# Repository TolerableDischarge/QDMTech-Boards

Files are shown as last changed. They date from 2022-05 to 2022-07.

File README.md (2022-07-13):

# QDMTech-Boards
A repo of all the boards designed by QuantumDarkMatter Tech.
v0.1 is very bad since I was learning as I was going for my Uni Project. There's a first time for everything I guess.
IMPORTANT: Right now the only thing under MIT license is the ZMK firmware files, the rest is a little murky. v0.2 will be MIT compatible.

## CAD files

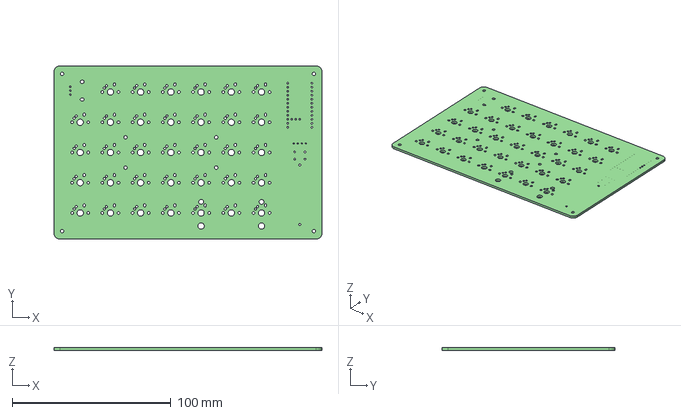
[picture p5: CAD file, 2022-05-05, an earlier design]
mk_01/v0.1/Hardware/mk_01_LHS/mk_01_LHS.step
168.9 x 109.2 x 1.60 mm

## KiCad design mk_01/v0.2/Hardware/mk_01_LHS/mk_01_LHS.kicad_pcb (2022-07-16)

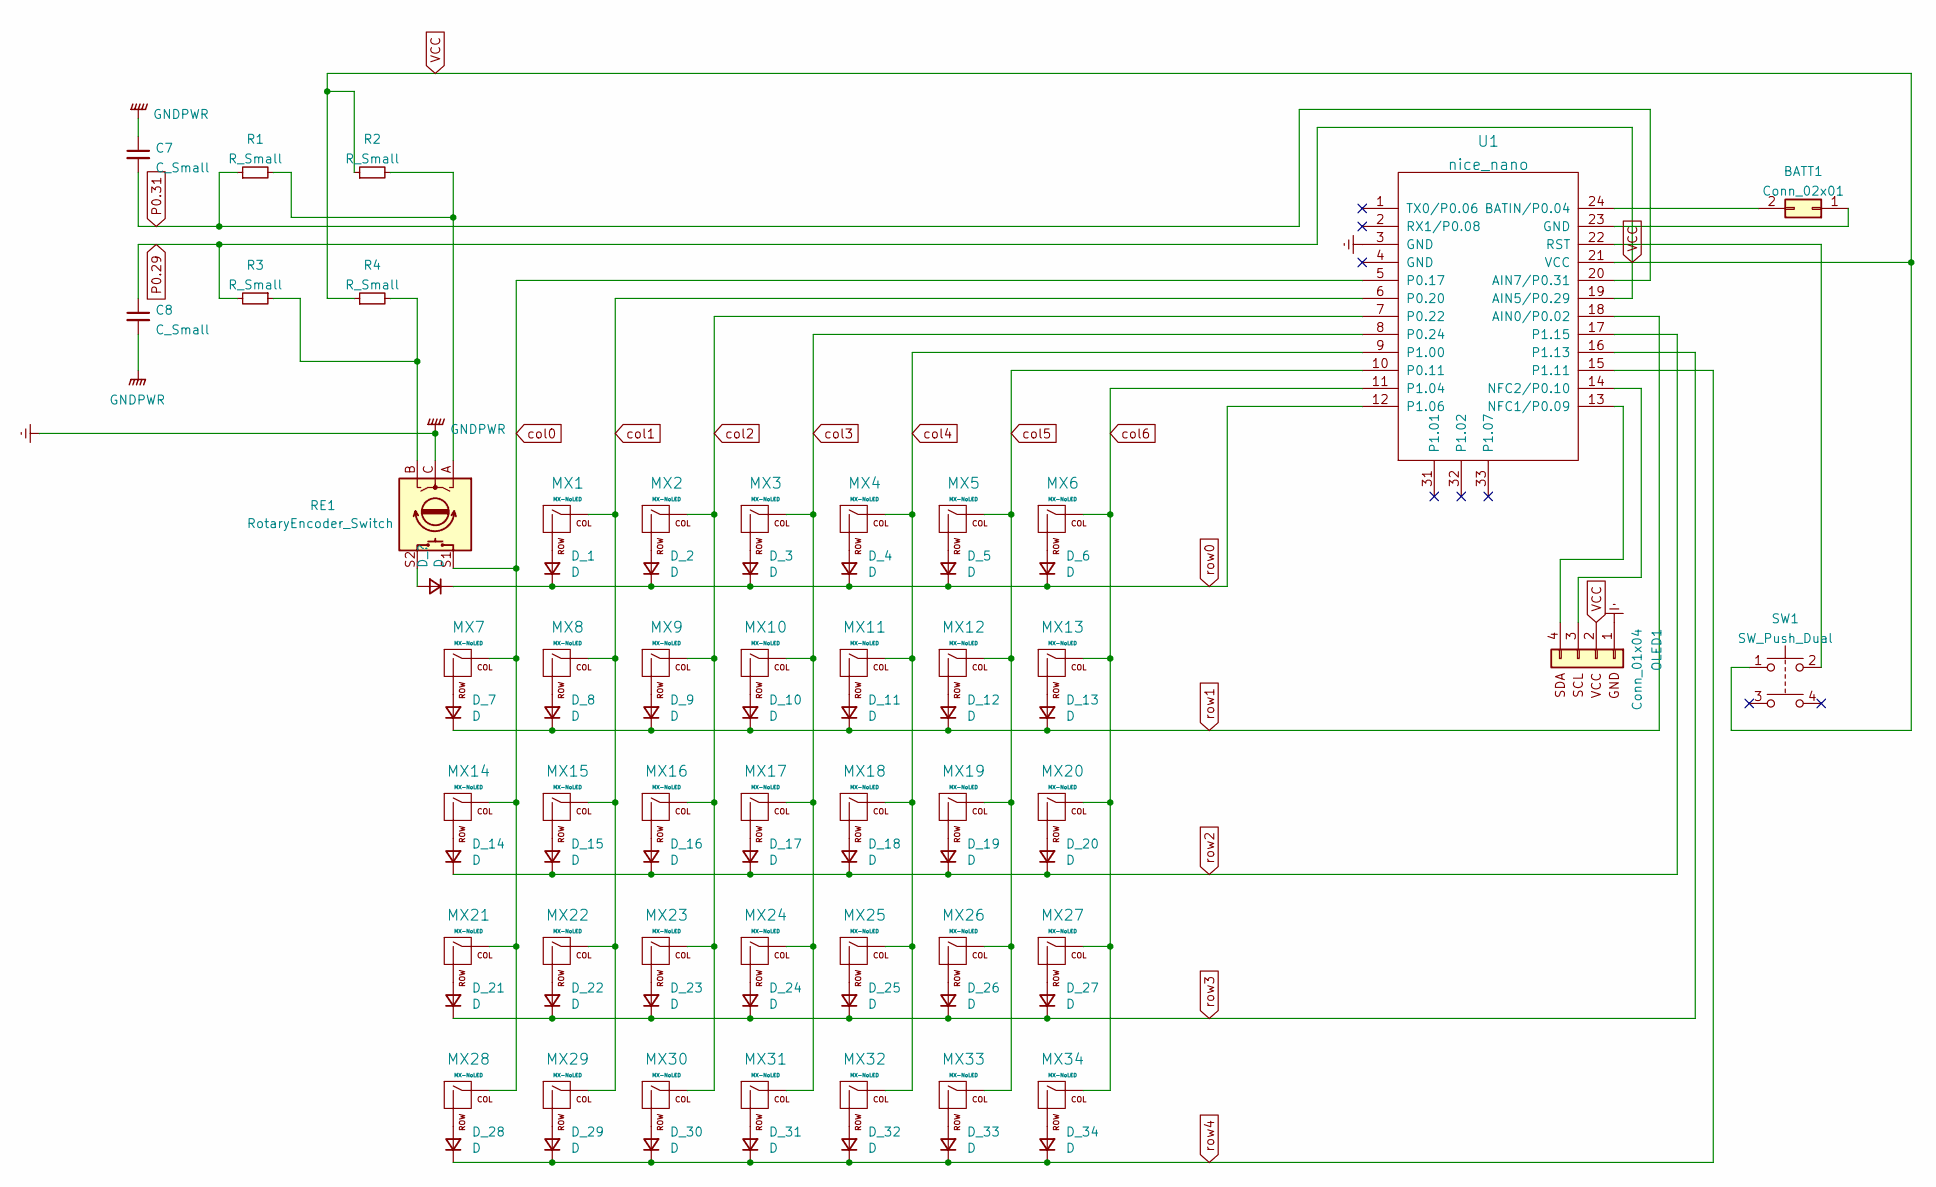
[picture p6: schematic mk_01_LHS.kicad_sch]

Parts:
BATT1: Conn_02x01; C_Rect_L41.5mm_W20.0mm_P37.50mm_MKS4
C7, C8: C_Small; C_0805_2012Metric_Pad1.18x1.45mm_HandSolder
D_1, D_2, D_3, D_4, D_5, D_6, D_7, D_8, D_9, D_10, D_11, D_12, D_13, D_14, D_15, D_16, D_17, D_18, D_19, D_20, D_21, D_22, D_23, D_24, D_25, D_26, D_27, D_28, D_29, D_30, D_31, D_32, D_33, D_34: D; D_SOD-123
MX1, MX2, MX3, MX4, MX5, MX6, MX7, MX8, MX9, MX10, MX11, MX12, MX13, MX14, MX15, MX16, MX17, MX18, MX19, MX20, MX21, MX22, MX23, MX24, MX25, MX26, MX27, MX28, MX29, MX30, MX31, MX32, MX33, MX34: MX-NoLED; MXOnly-1U-Hotswap-NoLED
OLED1: Conn_01x04; OLED_4Pin
R1, R2, R3, R4: R_Small; R_0805_2012Metric_Pad1.20x1.40mm_HandSolder
RE1: RotaryEncoder_Switch; RotaryEncoder_Alps_EC11E-Switch_Vertical_H20mm
SW1: SW_Push_Dual; SW_PUSH_6mm_H5mm
U1: nice_nano

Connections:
Earth: C7.1, C8.2, OLED1.1, RE1.C, U1.3 (GND), U1.4 (GND)
unnamed: BATT1.1, U1.23 (GND)
unnamed: BATT1.2, U1.24 (BATIN/P0.04)
unnamed: D_1.2 (A), MX1.2 (ROW)
unnamed: D_2.2 (A), MX2.2 (ROW)
unnamed: D_3.2 (A), MX3.2 (ROW)
unnamed: D_4.2 (A), MX4.2 (ROW)
unnamed: D_5.2 (A), MX5.2 (ROW)
unnamed: D_6.2 (A), MX6.2 (ROW)
unnamed: D_7.2 (A), MX7.2 (ROW)
unnamed: D_8.2 (A), MX8.2 (ROW)
unnamed: D_9.2 (A), MX9.2 (ROW)
unnamed: D_10.2 (A), MX10.2 (ROW)
unnamed: D_11.2 (A), MX11.2 (ROW)
unnamed: D_12.2 (A), MX12.2 (ROW)
unnamed: D_13.2 (A), MX13.2 (ROW)
unnamed: D_14.2 (A), MX14.2 (ROW)
unnamed: D_15.2 (A), MX15.2 (ROW)
unnamed: D_16.2 (A), MX16.2 (ROW)
unnamed: D_17.2 (A), MX17.2 (ROW)
unnamed: D_18.2 (A), MX18.2 (ROW)
unnamed: D_19.2 (A), MX19.2 (ROW)
unnamed: D_20.2 (A), MX20.2 (ROW)
unnamed: D_21.2 (A), MX21.2 (ROW)
unnamed: D_22.2 (A), MX22.2 (ROW)
unnamed: D_23.2 (A), MX23.2 (ROW)
unnamed: D_24.2 (A), MX24.2 (ROW)
unnamed: D_25.2 (A), MX25.2 (ROW)
unnamed: D_26.2 (A), MX26.2 (ROW)
unnamed: D_27.2 (A), MX27.2 (ROW)
unnamed: D_28.2 (A), MX28.2 (ROW)
unnamed: D_29.2 (A), MX29.2 (ROW)
unnamed: D_30.2 (A), MX30.2 (ROW)
unnamed: D_31.2 (A), MX31.2 (ROW)
unnamed: D_32.2 (A), MX32.2 (ROW)
unnamed: D_33.2 (A), MX33.2 (ROW)
unnamed: D_34.2 (A), MX34.2 (ROW)
unnamed: OLED1.3, U1.14 (NFC2/P0.10)
unnamed: OLED1.4, U1.13 (NFC1/P0.09)
unnamed: R1.2, R2.2, RE1.A
unnamed: R3.1, R4.2, RE1.B
unnamed 41: RE1.S2; also elsewhere on the board
unnamed: SW1.2, U1.22 (RST)
P0.31: C7.2, R1.1, U1.20 (AIN7/P0.31)
col0: MX7.1 (COL), MX14.1 (COL), MX21.1 (COL), MX28.1 (COL), RE1.S1, U1.5 (P0.17)
col1: MX1.1 (COL), MX8.1 (COL), MX15.1 (COL), MX22.1 (COL), MX29.1 (COL), U1.6 (P0.20)
col2: MX2.1 (COL), MX9.1 (COL), MX16.1 (COL), MX23.1 (COL), MX30.1 (COL), U1.7 (P0.22)
col3: MX3.1 (COL), MX10.1 (COL), MX17.1 (COL), MX24.1 (COL), MX31.1 (COL), U1.8 (P0.24)
col4: MX4.1 (COL), MX11.1 (COL), MX18.1 (COL), MX25.1 (COL), MX32.1 (COL), U1.9 (P1.00)
col5: MX5.1 (COL), MX12.1 (COL), MX19.1 (COL), MX26.1 (COL), MX33.1 (COL), U1.10 (P0.11)
col6: MX6.1 (COL), MX13.1 (COL), MX20.1 (COL), MX27.1 (COL), MX34.1 (COL), U1.11 (P1.04)
row0: D_1.1 (K), D_2.1 (K), D_3.1 (K), D_4.1 (K), D_5.1 (K), D_6.1 (K), U1.12 (P1.06); also elsewhere on the board
row1: D_7.1 (K), D_8.1 (K), D_9.1 (K), D_10.1 (K), D_11.1 (K), D_12.1 (K), D_13.1 (K), U1.18 (AIN0/P0.02)
row2: D_14.1 (K), D_15.1 (K), D_16.1 (K), D_17.1 (K), D_18.1 (K), D_19.1 (K), D_20.1 (K), U1.17 (P1.15)
row3: D_21.1 (K), D_22.1 (K), D_23.1 (K), D_24.1 (K), D_25.1 (K), D_26.1 (K), D_27.1 (K), U1.16 (P1.13)
row4: D_28.1 (K), D_29.1 (K), D_30.1 (K), D_31.1 (K), D_32.1 (K), D_33.1 (K), D_34.1 (K), U1.15 (P1.11)

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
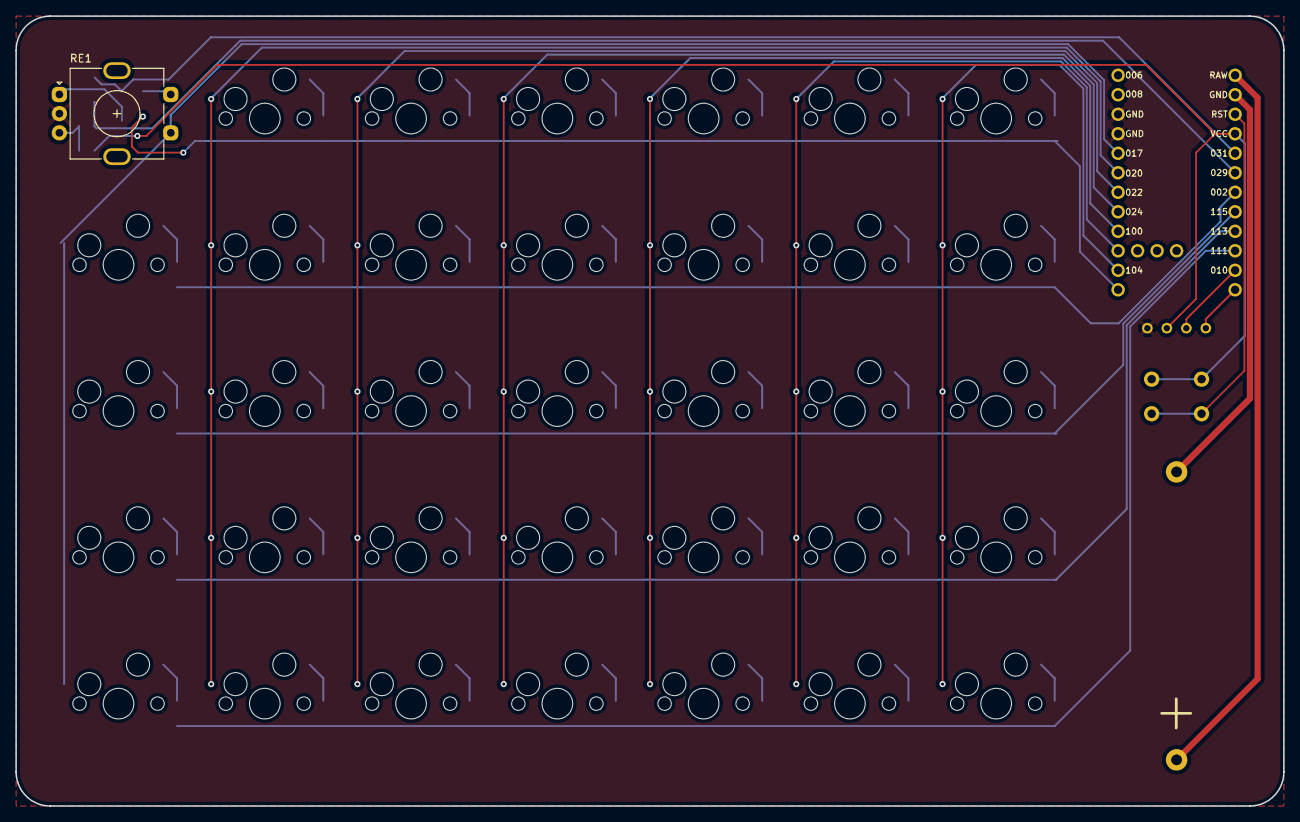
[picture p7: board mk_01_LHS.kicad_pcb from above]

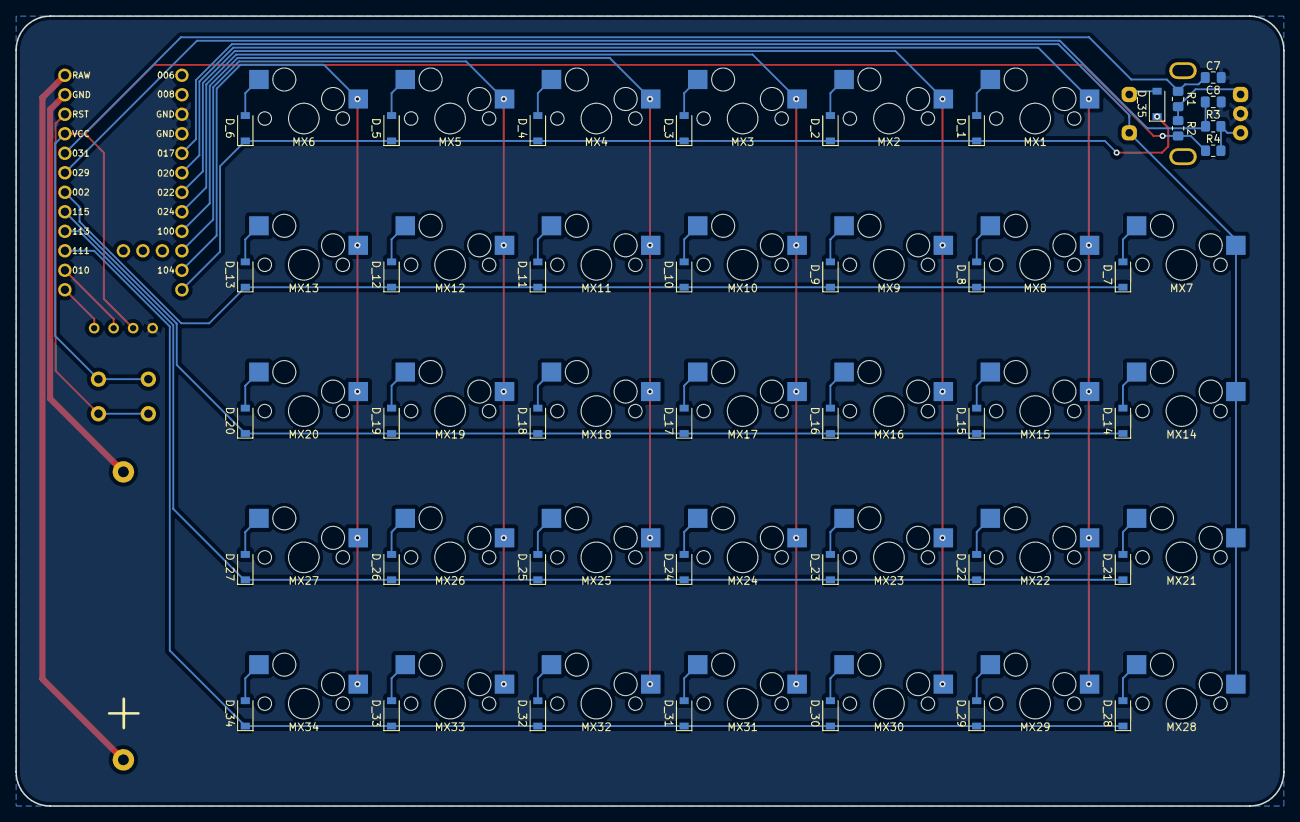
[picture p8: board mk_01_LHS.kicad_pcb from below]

Board: 2 copper layers, 165.1 x 102.9 mm, 80 parts (41 on the bottom side), 58 nets.

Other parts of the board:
D_35: D; D_SOD-123

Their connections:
unnamed 41: D_35.2 (A); also elsewhere on the board
row0: D_35.1 (K); also elsewhere on the board

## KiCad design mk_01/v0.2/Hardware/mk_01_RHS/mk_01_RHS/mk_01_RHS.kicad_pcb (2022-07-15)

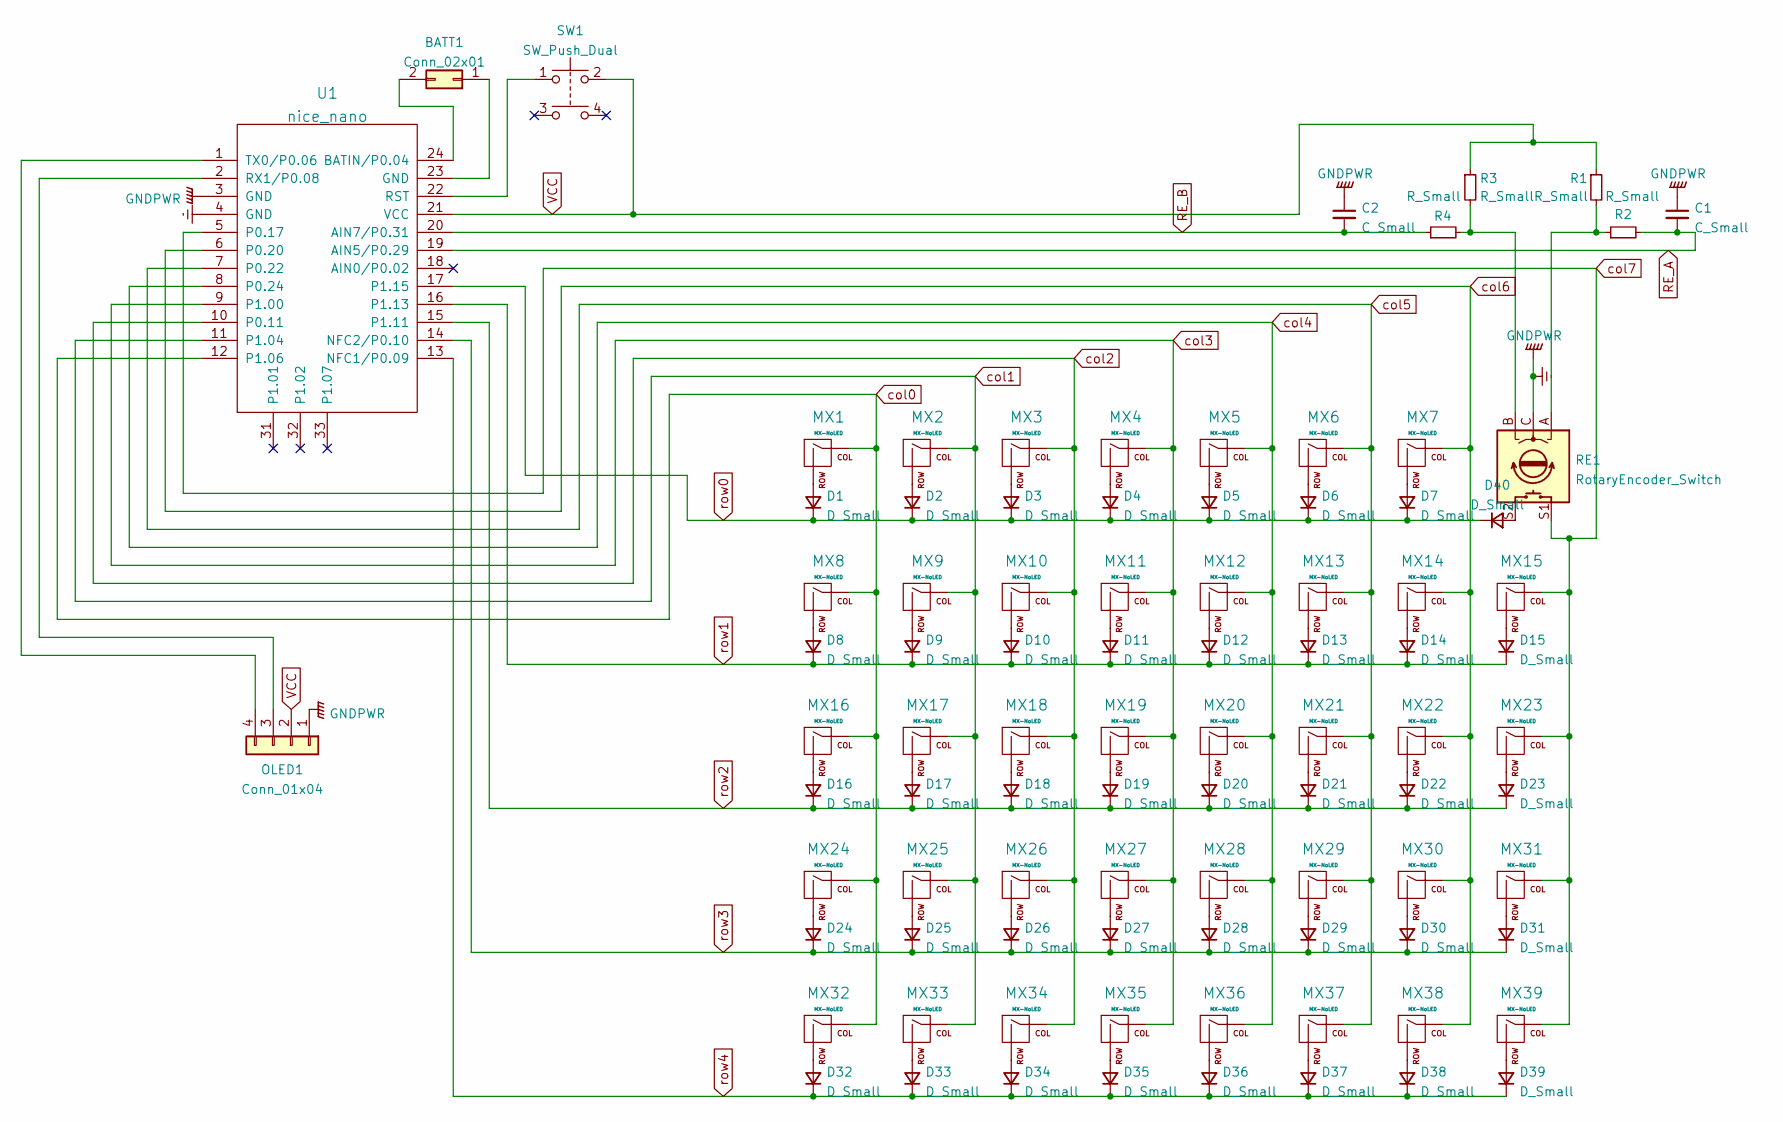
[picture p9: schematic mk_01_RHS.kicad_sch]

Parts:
BATT1: Conn_02x01; C_Rect_L41.5mm_W20.0mm_P37.50mm_MKS4
C1, C2: C_Small; C_0805_2012Metric_Pad1.18x1.45mm_HandSolder
D1, D2, D3, D4, D5, D6, D7, D8, D9, D10, D11, D12, D13, D14, D15, D16, D17, D18, D19, D20, D21, D22, D23, D24, D25, D26, D27, D28, D29, D30, D31, D32, D33, D34, D35, D36, D37, D38, D39, D40: D_Small; D_SOD-123
MX1, MX2, MX3, MX4, MX5, MX6, MX7, MX8, MX9, MX10, MX11, MX12, MX13, MX14, MX15, MX16, MX17, MX18, MX19, MX20, MX21, MX22, MX23, MX24, MX25, MX26, MX27, MX28, MX29, MX30, MX31, MX32, MX33, MX34, MX35, MX36, MX37, MX38, MX39: MX-NoLED; MXOnly-1U-Hotswap-NoLED
OLED1: Conn_01x04; OLED_4Pin
R1, R2, R3, R4: R_Small; R_0805_2012Metric_Pad1.20x1.40mm_HandSolder
RE1: RotaryEncoder_Switch; RotaryEncoder_Alps_EC11E-Switch_Vertical_H20mm
SW1: SW_Push_Dual; SW_PUSH_6mm_H5mm
U1: nice_nano

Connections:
Earth: C1.1, C2.1, OLED1.1, RE1.C, U1.3 (GND), U1.4 (GND)
unnamed: BATT1.1, U1.23 (GND)
unnamed: BATT1.2, U1.24 (BATIN/P0.04)
unnamed: D1.2 (A), MX1.2 (ROW)
unnamed: D2.2 (A), MX2.2 (ROW)
unnamed: D3.2 (A), MX3.2 (ROW)
unnamed: D4.2 (A), MX4.2 (ROW)
unnamed: D5.2 (A), MX5.2 (ROW)
unnamed: D6.2 (A), MX6.2 (ROW)
unnamed: D7.2 (A), MX7.2 (ROW)
unnamed: D8.2 (A), MX8.2 (ROW)
unnamed: D9.2 (A), MX9.2 (ROW)
unnamed: D10.2 (A), MX10.2 (ROW)
unnamed: D11.2 (A), MX11.2 (ROW)
unnamed: D12.2 (A), MX12.2 (ROW)
unnamed: D13.2 (A), MX13.2 (ROW)
unnamed: D14.2 (A), MX14.2 (ROW)
unnamed: D15.2 (A), MX15.2 (ROW)
unnamed: D16.2 (A), MX16.2 (ROW)
unnamed: D17.2 (A), MX17.2 (ROW)
unnamed: D18.2 (A), MX18.2 (ROW)
unnamed: D19.2 (A), MX19.2 (ROW)
unnamed: D20.2 (A), MX20.2 (ROW)
unnamed: D21.2 (A), MX21.2 (ROW)
unnamed: D22.2 (A), MX22.2 (ROW)
unnamed: D23.2 (A), MX23.2 (ROW)
unnamed: D24.2 (A), MX24.2 (ROW)
unnamed: D25.2 (A), MX25.2 (ROW)
unnamed: D26.2 (A), MX26.2 (ROW)
unnamed: D27.2 (A), MX27.2 (ROW)
unnamed: D28.2 (A), MX28.2 (ROW)
unnamed: D29.2 (A), MX29.2 (ROW)
unnamed: D30.2 (A), MX30.2 (ROW)
unnamed: D31.2 (A), MX31.2 (ROW)
unnamed: D32.2 (A), MX32.2 (ROW)
unnamed: D33.2 (A), MX33.2 (ROW)
unnamed: D34.2 (A), MX34.2 (ROW)
unnamed: D35.2 (A), MX35.2 (ROW)
unnamed: D36.2 (A), MX36.2 (ROW)
unnamed: D37.2 (A), MX37.2 (ROW)
unnamed: D38.2 (A), MX38.2 (ROW)
unnamed: D39.2 (A), MX39.2 (ROW)
unnamed: D40.2 (A), RE1.S2
unnamed: R3.2, R4.2, RE1.B
unnamed: R1.2, R2.1, RE1.A
unnamed: SW1.1, U1.22 (RST)
unnamed: OLED1.4, U1.1 (TX0/P0.06)
unnamed: OLED1.3, U1.2 (RX1/P0.08)
RE_A: C1.2, R2.2, U1.19 (AIN5/P0.29)
RE_B: C2.2, R4.1, U1.20 (AIN7/P0.31)
VCC: OLED1.2, R1.1, R3.1, SW1.2, U1.21 (VCC)
col0: MX1.1 (COL), MX8.1 (COL), MX16.1 (COL), MX24.1 (COL), MX32.1 (COL), U1.12 (P1.06)
col1: MX2.1 (COL), MX9.1 (COL), MX17.1 (COL), MX25.1 (COL), MX33.1 (COL), U1.11 (P1.04)
col2: MX3.1 (COL), MX10.1 (COL), MX18.1 (COL), MX26.1 (COL), MX34.1 (COL), U1.10 (P0.11)
col3: MX4.1 (COL), MX11.1 (COL), MX19.1 (COL), MX27.1 (COL), MX35.1 (COL), U1.9 (P1.00)
col4: MX5.1 (COL), MX12.1 (COL), MX20.1 (COL), MX28.1 (COL), MX36.1 (COL), U1.8 (P0.24)
col5: MX6.1 (COL), MX13.1 (COL), MX21.1 (COL), MX29.1 (COL), MX37.1 (COL), U1.7 (P0.22)
col6: MX7.1 (COL), MX14.1 (COL), MX22.1 (COL), MX30.1 (COL), MX38.1 (COL), U1.6 (P0.20)
col7: MX15.1 (COL), MX23.1 (COL), MX31.1 (COL), MX39.1 (COL), RE1.S1, U1.5 (P0.17)
row0: D1.1 (K), D2.1 (K), D3.1 (K), D4.1 (K), D5.1 (K), D6.1 (K), D7.1 (K), D40.1 (K), U1.17 (P1.15)
row1: D8.1 (K), D9.1 (K), D10.1 (K), D11.1 (K), D12.1 (K), D13.1 (K), D14.1 (K), D15.1 (K), U1.16 (P1.13)
row2: D16.1 (K), D17.1 (K), D18.1 (K), D19.1 (K), D20.1 (K), D21.1 (K), D22.1 (K), D23.1 (K), U1.15 (P1.11)
row3: D24.1 (K), D25.1 (K), D26.1 (K), D27.1 (K), D28.1 (K), D29.1 (K), D30.1 (K), D31.1 (K), U1.14 (NFC2/P0.10)
row4: D32.1 (K), D33.1 (K), D34.1 (K), D35.1 (K), D36.1 (K), D37.1 (K), D38.1 (K), D39.1 (K), U1.13 (NFC1/P0.09)

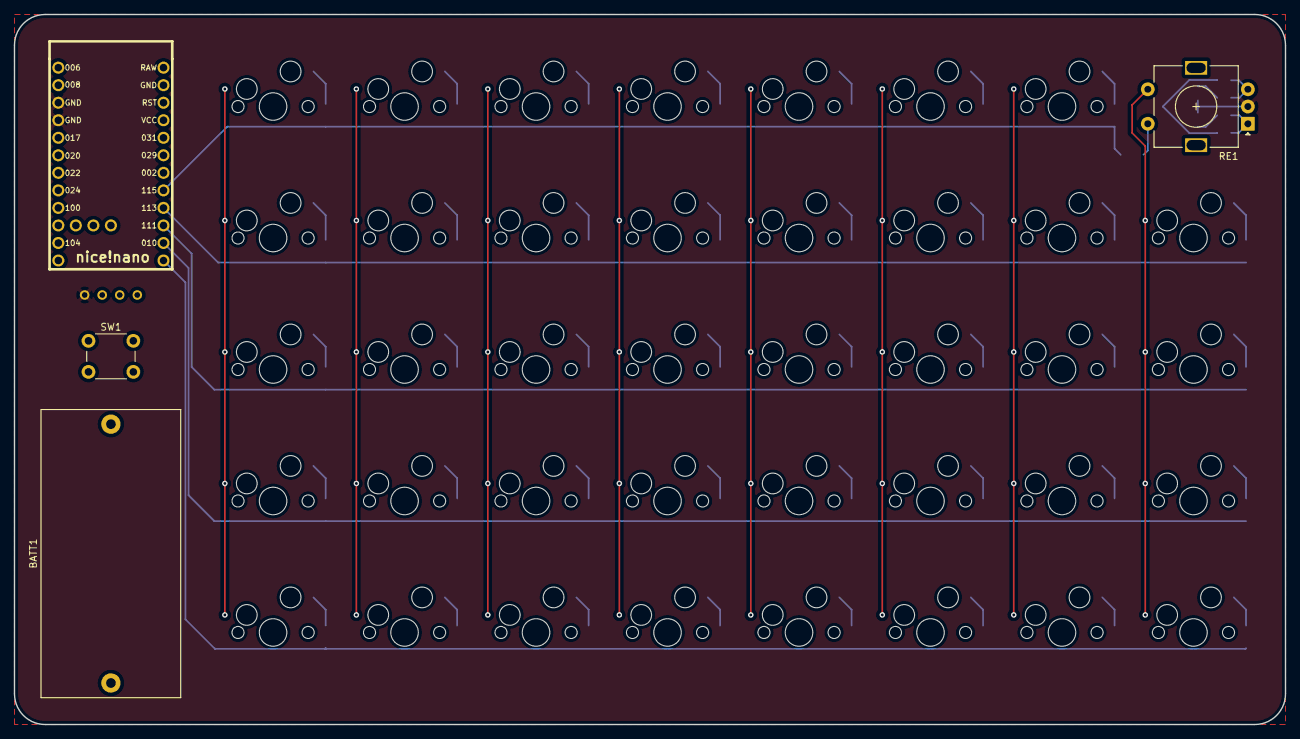
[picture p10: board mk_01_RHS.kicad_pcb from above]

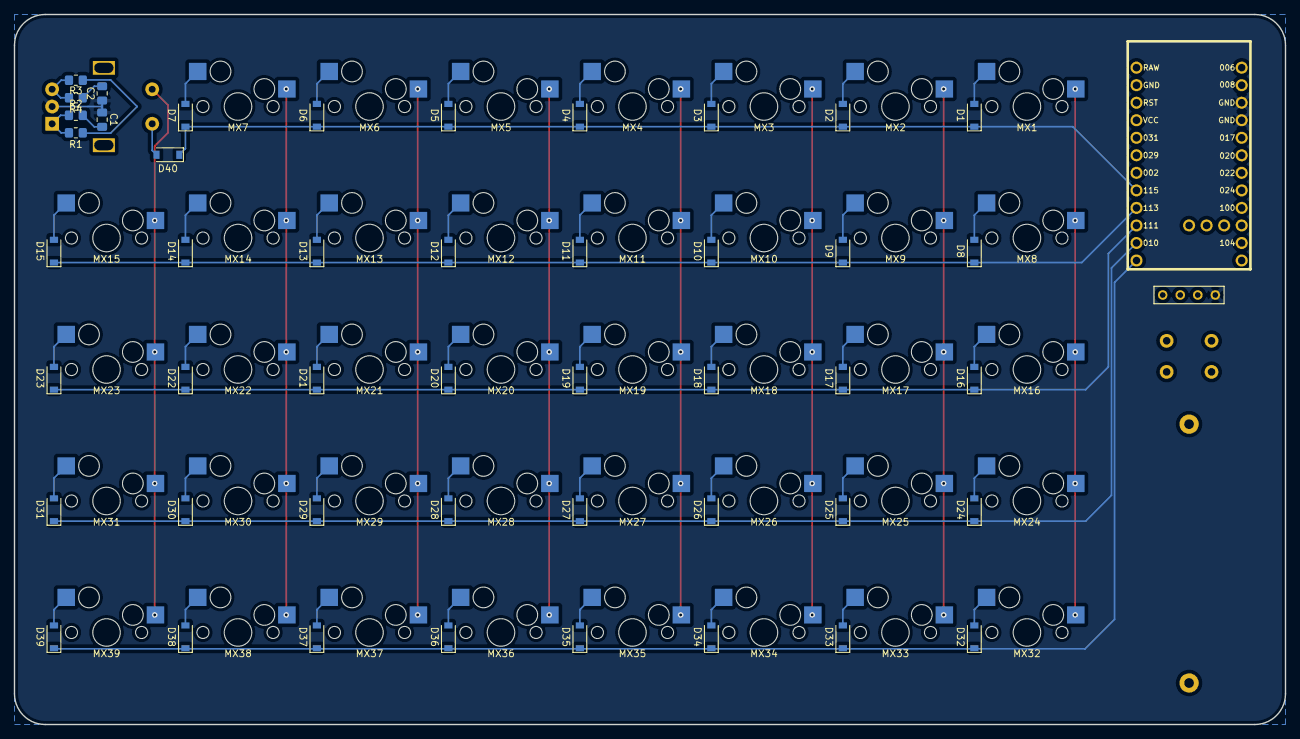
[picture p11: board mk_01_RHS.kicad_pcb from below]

Board: 2 copper layers, 184.1 x 102.9 mm, 90 parts (46 on the bottom side), 64 nets.

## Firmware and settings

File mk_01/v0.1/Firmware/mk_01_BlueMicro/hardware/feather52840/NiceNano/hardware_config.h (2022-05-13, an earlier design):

/*
Copyright 2018-2021 <Pierre Constantineau>

3-Clause BSD License

Redistribution and use in source and binary forms, with or without modification, are permitted provided that the following conditions are met:

1. Redistributions of source code must retain the above copyright notice, this list of conditions and the following disclaimer.

2. Redistributions in binary form must reproduce the above copyright notice, this list of conditions and the following disclaimer in the documentation and/or other materials provided with the distribution.

3. Neither the name of the copyright holder nor the names of its contributors may be used to endorse or promote products derived from this software without specific prior written permission.

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
*/
#ifndef HARDWARE_CONFIG_H
#define HARDWARE_CONFIG_H
#include "hardware_variants.h"
/* HARDWARE DEFINITION*/
/* key matrix size */
#define MATRIX_ROWS 5
#define MATRIX_COLS 7

#define MATRIX_ROW_PINS {47, 45, 43, 10, 9 }
#define MATRIX_COL_PINS {39, 34, 33, 31, 11, 36, 38}
#define UNUSED_PINS {6, 8, 17 }

/* COL2ROW or ROW2COL */
#define DIODE_DIRECTION COL2ROW
#define BATTERY_TYPE BATT_LIPO
#define VBAT_PIN 4
#define VCC_PIN 13
#define VCC_POLARITY_ON 0

//#define STATUS_BLE_LED_PIN  15  //blue = 0.15
//#define BLE_LED_ACTIVE 1
//#define BLE_LED_POLARITY 1

//#define WS2812B_LED_PIN 24
//#define WS2812B_LED_COUNT 6
//#define WS2812B_LED_ON 1

//#define I2C_SDA_PIN 22
//#define I2C_SCK_PIN 20
//#define DISPLAY_U8G2_CONSTRUCTOR U8G2_SSD1305_128X32_NONAME_1_SW_I2C

//#define ENCODER_A_PIN 31
//#define ENCODER_B_PIN 29
//#define ENCODER_RESOLUTION 1

#endif /* HARDWARE_CONFIG_H */

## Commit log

2022-05-05 Uploading the hardware
    Since I discovered version control very late in the development process, these files are very very messy and badly organised. Next version will be much better learning from the mistakes I made.
    [Keyboard Left Hand Side kinda fucked.kicad_sch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]
2022-05-13 Updates
    Incldues updates to ZMK and the creation of the BlueMicro firmware folder
    [mk_01_LHS.kicad_sch]
2022-07-12 v0.2 Started plus housekeeping
    I've started redesigning v0.1 into something better with v0.2. This time I'm going to ignore RGB lighting with the goal of completing a working product first, then adding extra features in the future. I've also cleaned up the file structure a bit, however I'll keep making edits so the folders aren't the confusing mess they're in right now.
    [mk_01_LHS.kicad_sch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]
2022-07-13 Hardware updates
    Keyboard matrix is complete, on both the schematic and the board design. To keep the design simple, I will remove the LEDs.
    [mk_01_LHS.kicad_pcb, mk_01_LHS.kicad_sch]
2022-07-13 LED removal and progress
    The LEDs have been removed from the schematic and the board design, edge cuts and routing for the key matrix have been added, as has the capacitor|resistor layout for the rotary encoder (which I may replace with an ec11 for push button functionality). The other components have also been arranged into their correct positions.
    [mk_01_LHS.kicad_pcb]
2022-07-13 Updated PCB design
    The PCB design has been updated and is now relatively complete. The hardware is fully MIT compliant, as all libraries used are under MIT license, and the design is entirely my own. Now it's time to r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
    [mk_01_LHS.kicad_pcb]
2022-07-13 Updated schematic
    Updated schematic that was meant to be included in the last commit.
    [mk_01_LHS.kicad_sch]
2022-07-14 PCB completed and rounded
    The PCB is pretty much complete for the left hand side, and I've generated a seperate file with rounded tracks using the round tracks plugin.
    [mk_01_LHS-rounded.kicad_pcb]
2022-07-14 Finalising layout and troubleshooting round-tracks
    The layout is pretty much complete, with all necessary components wired correctly. round-tracks keeps refusing to round one of the traces. A label free version has been added, however I'll probably remove this since it means two designs to constantly keep up to date.
    [mk_01_LHS-label-free.kicad_pcb, mk_01_LHS.kicad_pcb, mk_01_LHS.kicad_sch]
2022-07-15 Left Hand Side completion and housekeeping
    The left hand side has been completed, time to start on the right hand side. I've cleared out the right hand side files, because this time I'm going to start from scratch.
    [mk_01_LHS-rounded.kicad_pcb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]
2022-07-15 Starting the right hand side
    The right hand side schematic has been completed, subject to change based on the board design. The board design has also already been started.
    [mk_01_LHS.kicad_sch, mk_01_RHS.kicad_pcb, mk_01_RHS.kicad_sch]
2022-07-16 Right hand side mostly completed
    The right hand side of the keyboard is pretty much complete, and after a final checkover of everything I think it's ready for production. I'm going to clean up the left hand side board design and sch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
    [mk_01_LHS-rounded.kicad_pcb, mk_01_LHS.kicad_pcb, mk_01_RHS-rounded.kicad_pcb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]
